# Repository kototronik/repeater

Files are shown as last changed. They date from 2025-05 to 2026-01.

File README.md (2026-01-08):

# Репитер на базе ESP32
## ⚠️ 

Проект больше не поддерживается.
Дальнейшее развитие и обновления не планируются.

---

## Основные возможности

- Повторение аналоговых FM-сигналов  
- Совместимость с радиостанциями с 6-пиновым разъёмом **Kenwood** (Baofeng, Kenwood, Quansheng и др.)  
- Подходит для стационарного и мобильного использования  

---

## Основные компоненты

- **Микроконтроллер** ESP32  
- **Радиостанция** с разъёмом Kenwood  
- **Источник питания** 5В  
- **Схема согласования и развязки аудиосигналов** (см. ниже)  
- **Внешний ЦАП** PCM5102A *(опционально)*  

---

## Схема подключения разъёма Kenwood

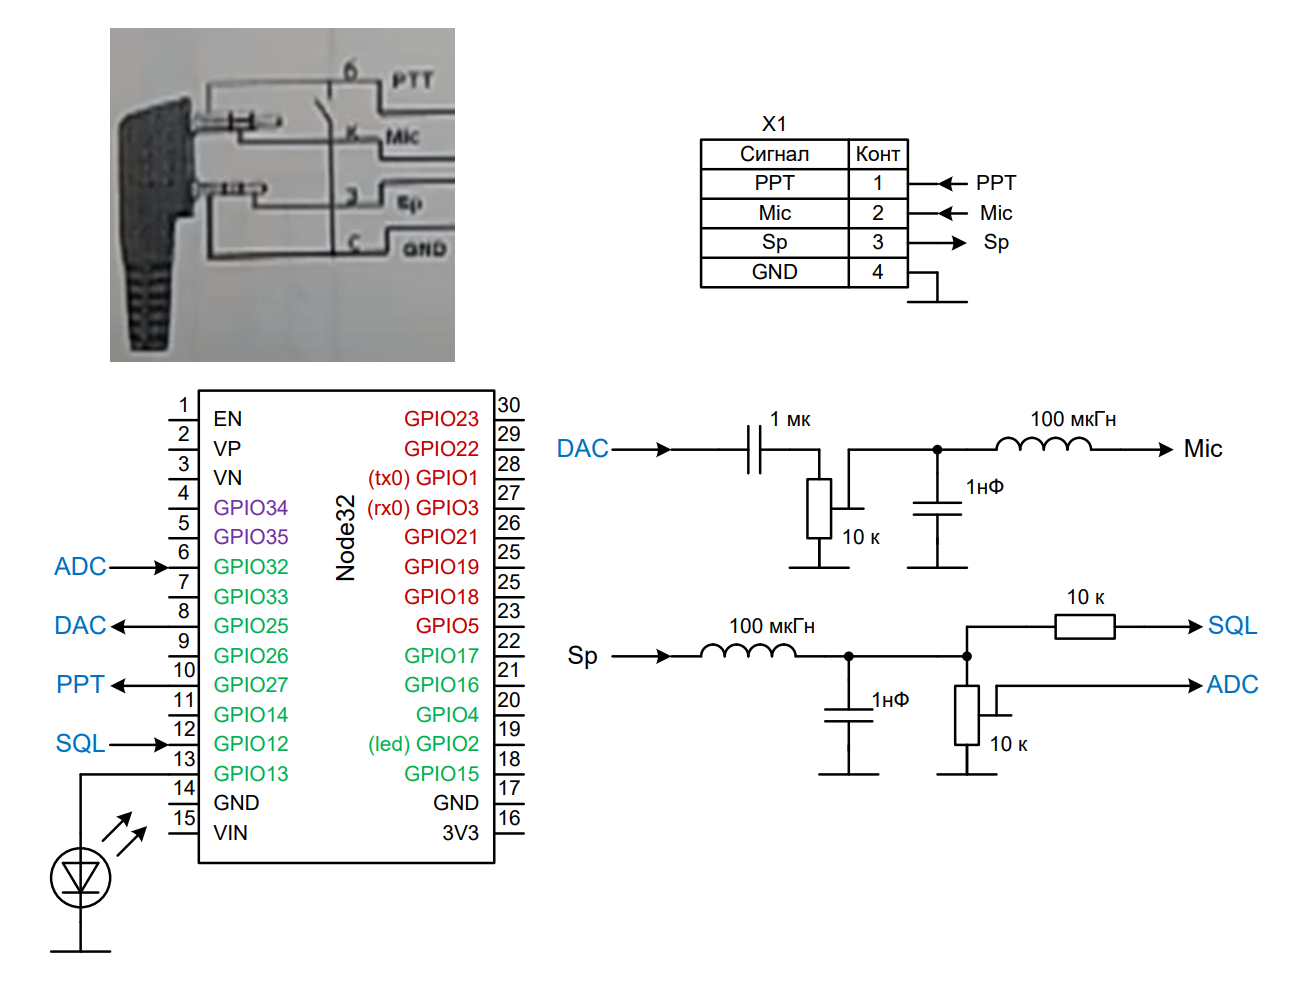
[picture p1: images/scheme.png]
Схема подключения разъема Kenwood


> **Примечание:** в версии с внешним ЦАПом пин **PTT = GPIO 32**

---

## Подключение SD-карты

| **SD-карта** | **ESP32** |
|---|---|
| CS | GPIO 5 |
| SCK | GPIO 18 |
| MOSI (SDI) | GPIO 23 |
| MISO (SDO) | GPIO 19 |
| VCC | 3.3В *(или 5В)* |
| GND | GND |

---

## Подключение внешнего ЦАП (PCM5102A)

| **ЦАП PCM5102A** | **ESP32** |
|---|---|
| DIN (DOUT) | GPIO 25 |
| BCK (BCLK) | GPIO 27 |
| LCK (LRCK) | GPIO 26 |
| VCC | 3.3В |
| GND | GND |

---

## Работоспособность

- **Встроенный ЦАП ESP32**  
  Работает, но присутствуют искажения и посторонние шумы. При слабом входном сигнале — плохая разборчивость речи.  

- **Внешний ЦАП (PCM5102A)**  
 При хорошем экранировании — качественное звучание.  

---

## Корпус

3D-модели корпуса и крышки находятся в папке `3D` (формат `.stp`).

---

## Источник

Проект основан на работе [Печенова Александра (ФГБОУ ВО "ДОННТУ", г. Донецк)](https://disk.yandex.ru/d/aPEOfnw8R4aH_Q).

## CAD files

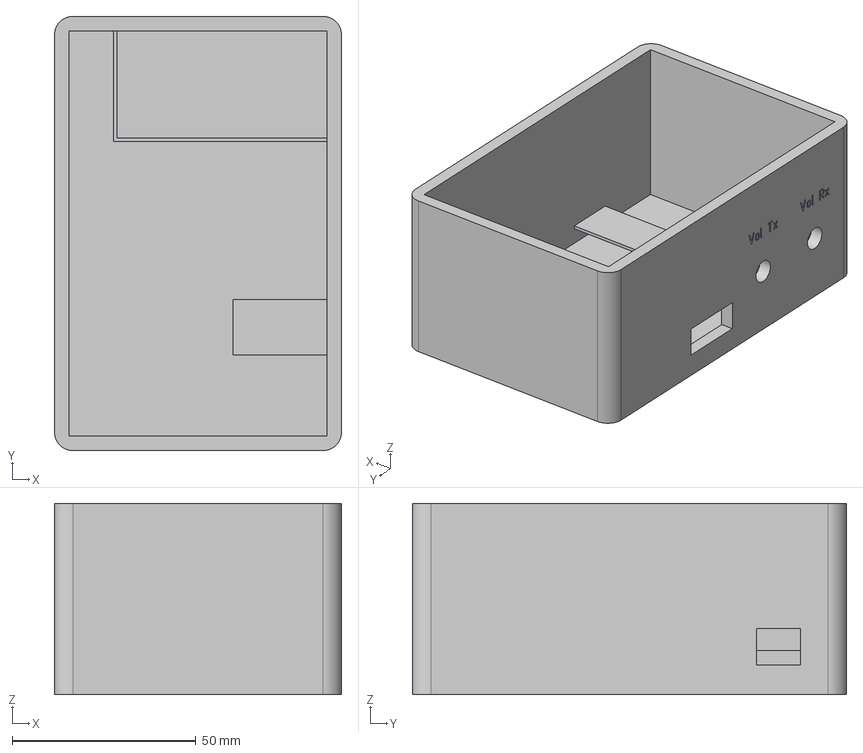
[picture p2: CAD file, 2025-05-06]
3D/репитер коробка.stp
78.0 x 118.0 x 52.0 mm

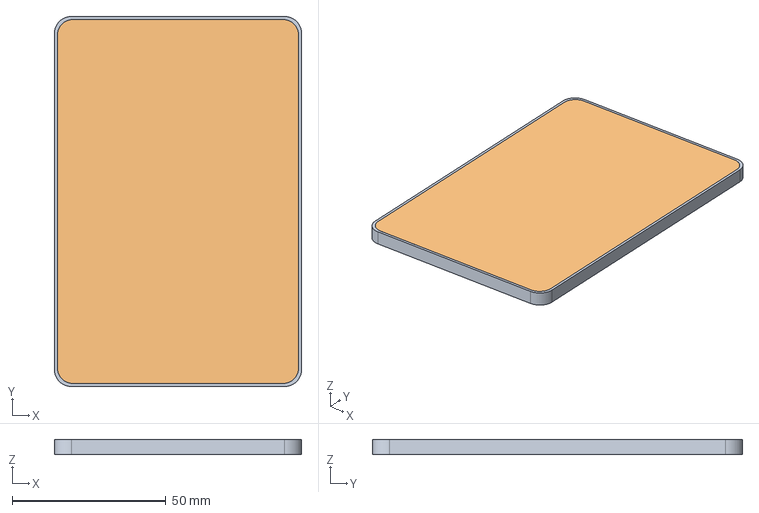
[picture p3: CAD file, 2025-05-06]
3D/крышка.stp
80.5 x 120.5 x 5.00 mm

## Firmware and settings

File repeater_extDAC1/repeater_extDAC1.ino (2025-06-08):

#include <Arduino.h>

#include <SD.h>

#include <FS.h>

#include "driver/i2s.h"

// === Константы ===

// === Настройки I2S ===
#define I2S_SAMPLE_RATE 22050 // Частота дискретизации
#define I2S_SAMPLE_BITS 16 // Битность выборки
#define I2S_CHANNEL_NUM 1
#define I2S_BUFFER_LEN 1024 // Размер буфера I2S

// === Пины подключения радиостанции ===
#define pinPPT 32
#define pinSQL 12

// === Пины подключения SD-карты и I2S ===
#define SD_CS_PIN 5
#define I2S_DOUT_PIN 25
#define I2S_BCLK_PIN 27
#define I2S_LRCK_PIN 26

const char * audioFileName = "/recording.wav"; // Имя файла для записи
File audioFile;

bool Rec = false; // Флаг записи

// === Конфигурация встроенного I2S (пин 36, ADC) ===
void setupI2S_Input() {
  i2s_config_t config = {
    .mode = (i2s_mode_t)(I2S_MODE_MASTER | I2S_MODE_RX | I2S_MODE_ADC_BUILT_IN),
    .sample_rate = I2S_SAMPLE_RATE,
    .bits_per_sample = I2S_BITS_PER_SAMPLE_16BIT,
    .channel_format = I2S_CHANNEL_FMT_ONLY_LEFT,
    .communication_format = I2S_COMM_FORMAT_STAND_I2S,
    .intr_alloc_flags = ESP_INTR_FLAG_LEVEL1,
    .dma_buf_count = 8,
    .dma_buf_len = I2S_BUFFER_LEN / 2,
    .use_apll = false,
    .tx_desc_auto_clear = false,
    .fixed_mclk = 0
  };
  i2s_driver_install(I2S_NUM_0, & config, 0, NULL);
  i2s_set_adc_mode(ADC_UNIT_1, ADC1_CHANNEL_0);
  i2s_adc_enable(I2S_NUM_0);
}

// === Конфигурация PCM5102A (DAC) ===
void setupI2S_Output() {
  i2s_config_t config = {
    .mode = (i2s_mode_t)(I2S_MODE_MASTER | I2S_MODE_TX),
    .sample_rate = I2S_SAMPLE_RATE,
    .bits_per_sample = I2S_BITS_PER_SAMPLE_16BIT,
    .channel_format = I2S_CHANNEL_FMT_ONLY_LEFT,
    .communication_format = I2S_COMM_FORMAT_STAND_I2S,
    .intr_alloc_flags = ESP_INTR_FLAG_LEVEL1,
    .dma_buf_count = 8,
    .dma_buf_len = I2S_BUFFER_LEN / 2,
    .use_apll = false,
    .tx_desc_auto_clear = true,
    .fixed_mclk = 0
  };
  i2s_driver_install(I2S_NUM_0, & config, 0, NULL);
  i2s_pin_config_t pin_config = {
    .bck_io_num = I2S_BCLK_PIN,
    .ws_io_num = I2S_LRCK_PIN,
    .data_out_num = I2S_DOUT_PIN,
    .data_in_num = I2S_PIN_NO_CHANGE
  };
  i2s_set_pin(I2S_NUM_0, & pin_config);
}

// === Прописывание wav заголовка ===
void writeWavHeader(File file, uint32_t dataSize) {
  uint32_t sampleRate = I2S_SAMPLE_RATE;
  uint16_t bitsPerSample = I2S_SAMPLE_BITS;
  uint16_t channels = I2S_CHANNEL_NUM;
  uint32_t byteRate = sampleRate * channels * (bitsPerSample / 8);
  uint16_t blockAlign = channels * (bitsPerSample / 8);
  uint32_t chunkSize = 36 + dataSize;

  file.seek(0);
  file.write((const uint8_t * )
    "RIFF", 4);
  file.write((uint8_t * ) & chunkSize, 4);
  file.write((const uint8_t * )
    "WAVE", 4);
  file.write((const uint8_t * )
    "fmt ", 4);

  uint32_t subchunk1Size = 16;
  uint16_t audioFormat = 1;

  file.write((uint8_t * ) & subchunk1Size, 4);
  file.write((uint8_t * ) & audioFormat, 2);
  file.write((uint8_t * ) & channels, 2);
  file.write((uint8_t * ) & sampleRate, 4);
  file.write((uint8_t * ) & byteRate, 4);
  file.write((uint8_t * ) & blockAlign, 2);
  file.write((uint8_t * ) & bitsPerSample, 2);
  file.write((const uint8_t * )
    "data", 4);
  file.write((uint8_t * ) & dataSize, 4);

}

// === Функция записи на карту ===
void recordWav() {
  uint8_t i2sBuffer[I2S_BUFFER_LEN];
  int16_t samples[I2S_BUFFER_LEN / 2];
  size_t bytesRead;
  uint32_t totalBytes = 0;

  float scaleFactor = 16.0f;
  float fc = 70.0f;
  float fs = I2S_SAMPLE_RATE;
  float RC = 1.0f / (2.0f * PI * fc);
  float alpha = RC / (RC + 1.0f / fs);

  int16_t x_prev = 0, y_prev = 0;

  Serial.println("Начинаем запись...");

  unsigned long lastSignalTime = millis(); // Время последнего сигнала
  const unsigned long signalTimeout = 1000; // Таймаут "тишины" в миллисекундах

  while (true) {
    bool signal = digitalRead(pinSQL);
    if (signal) {
      lastSignalTime = millis(); // Обновляем время последнего сигнала
    }

    if (millis() - lastSignalTime > signalTimeout) {
      // Если сигнал не поступает в течение заданного времени (1000 мс), завершаем запись
      break;
    }

    if (i2s_read(I2S_NUM_0, i2sBuffer, I2S_BUFFER_LEN, & bytesRead, portMAX_DELAY) != ESP_OK)
      continue;

    int sampleCount = bytesRead / 2;
    for (int i = 0; i < sampleCount; ++i) {
      uint16_t raw = ((uint16_t) i2sBuffer[i * 2 + 1] << 8) | i2sBuffer[i * 2];
      int16_t centered = (int16_t) raw - 2048;
      int32_t scaled = centered * scaleFactor;
      scaled = constrain(scaled, -32768, 32767);
      int16_t current = scaled;
      int16_t filtered = alpha * (y_prev + current - x_prev);
      x_prev = current;
      y_prev = filtered;
      samples[i] = filtered;
    }

    audioFile.write((uint8_t * ) samples, sampleCount * sizeof(int16_t));
    totalBytes += sampleCount * sizeof(int16_t);
  }

  Serial.println("Запись завершена.");
  writeWavHeader(audioFile, totalBytes);
}

// === Функция воспроизведения ===
void playWav(const char * filePath) {
  File file = SD.open(filePath, FILE_READ);
  if (!file || file.size() <= 44) {
    Serial.println("Ошибка WAV-файла.");
    return;
  }

  uint8_t buffer[I2S_BUFFER_LEN];
  size_t bytesRead, bytesWritten;

  Serial.print("Воспроизведение: ");
  Serial.println(filePath);

  file.seek(44); // Пропускаем заголовок WAV, так как и так знаем параметры записи, он нужен только для упрощения воспроизведения на компьютере
  while (file.available()) {
    bytesRead = file.read(buffer, I2S_BUFFER_LEN);
    i2s_write(I2S_NUM_0, buffer, bytesRead, & bytesWritten, portMAX_DELAY);
  }

  i2s_zero_dma_buffer(I2S_NUM_0);
  file.close();
  Serial.println("Готово.");
}

void setup() {
  Serial.begin(115200);

  pinMode(pinPPT, INPUT);
  pinMode(pinSQL, INPUT);

  Serial.print("SD карта: "); // Инициализация SD-карты
  if (!SD.begin(SD_CS_PIN)) {
    Serial.println("ошибка инициализации... проверьте подключение.");
    while (true);
  }
  Serial.println("репитер готов к исползованию!");

}

void loop() {
  bool SQL = digitalRead(pinSQL);

  //Условие для начала записи
  if (SQL && !Rec) {
    Rec = true;

    if (SD.exists(audioFileName)) SD.remove(audioFileName);
    audioFile = SD.open(audioFileName, FILE_WRITE);
    if (!audioFile) {
      Serial.println("Не удалось открыть файл.");
      return;
    }

    uint8_t header[44] = {
      0
    };
    audioFile.write(header, 44);

    setupI2S_Input();
    recordWav();
    i2s_adc_disable(I2S_NUM_0);
    i2s_driver_uninstall(I2S_NUM_0);
    audioFile.close();

    delay(500);

    pinMode(pinPPT, OUTPUT);
    setupI2S_Output();
    playWav(audioFileName); //Повторяем то, что записали
    playWav("/end2.wav"); //Воспроизводим сигнал окончания передачи
    i2s_driver_uninstall(I2S_NUM_0);

    Rec = false;
    pinMode(pinPPT, INPUT);
  }

}

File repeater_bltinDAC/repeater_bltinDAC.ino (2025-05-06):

#include <SD.h>

#include <FS.h>

#define dt 110 // Период квантования ЦАП, мкс
#define pinLED 2 // Встроенный светодиод
#define pinLED2 13 // Внешний светодиод
#define pinADC 32 // АЦП
#define pinDAC 25 // ЦАП
#define pinPPT 27 // Программный аналог кнопки PTT
#define pinSQL 12 // Триггер записи (радиостанция, при открытии шумоподавителя, посылает постоянный ток на этот пин)
#define morseFreq 1000 // Несущая частота морзянки (завершение передачи будет на этой частоте)

long T_dt; // Таймер воспроизведения
bool Rec = false; // Флаг записи

File audioFile;

void setup() {
  setCpuFrequencyMhz(40); //Включение экономии энергии

  pinMode(pinLED, OUTPUT);
  pinMode(pinLED2, OUTPUT);

  digitalWrite(pinLED2, 1);
  delay(1000);
  digitalWrite(pinLED2, 0);

  pinMode(pinPPT, INPUT);
  pinMode(pinSQL, INPUT);

  Serial.begin(9600);
  Serial.println("start");

  if (!SD.begin()) {
    Serial.println("Ошибка инициализации SD-карты!");
    return;
  }
  Serial.println("SD карта инициализирована");
}

void playMorseSymbol(bool isDot) {
  unsigned long duration = isDot ? 50 : 150; // 50 мс для точки, 150 мс для тире
  unsigned long startTime = millis();

  // Генерация сигнала с частотой morseFreq Гц (с использованием прямоугольного сигнала через ЦАП)
  while (millis() - startTime < duration) {
    dacWrite(pinDAC, 255); // Выводим высокий уровень (максимальное значение для аналогового сигнала, доступного для встроенного АЦП)
    delayMicroseconds(500); // Высокий уровень для полуволны
    dacWrite(pinDAC, 0); // Выводим низкий уровень
    delayMicroseconds(500); // Низкий уровень для полуволны
  }

  delay(50); // Интервал между символами
}

void playMorseCode() {
  // Морзянка для "*-*-*" (с быстрым интервалом между символами)
  playMorseSymbol(true);  // *
  playMorseSymbol(false); // -
  playMorseSymbol(true);  // *
  playMorseSymbol(false); // -
  playMorseSymbol(true);  // *
}

void loop() {
  bool SQL = digitalRead(pinSQL);
  digitalWrite(pinLED2, SQL); // Индикация записи

  // Начало записи
  if (SQL && !Rec) {
    Rec = true;
    setCpuFrequencyMhz(240); // Выход из режима экономии
    T_dt = micros();

    // Открываем файл для записи
    audioFile = SD.open("/audio.dat", FILE_WRITE);
    if (!audioFile) {
      Serial.println("Ошибка открытия файла для записи!");
      Rec = false;
      return;
    }

    Serial.println("Начало записи...");
  }

  // Запись данных на SD пока активен pinSQL
  unsigned long silenceStart = 0;

  while (Rec) {
    bool currentSQL = digitalRead(pinSQL);

    if (currentSQL) {
      silenceStart = 0; // сбрасываем таймер тишины

      if (micros() - T_dt >= dt) {
        T_dt = micros();
        byte value = analogRead(pinADC) / 16; // Преобразуем 12-бит в 8-бит
        audioFile.write(value);
      }
    } else {
      if (silenceStart == 0) {
        silenceStart = millis(); // фиксируем момент начала тишины
      } else if (millis() - silenceStart >= 1000) {
        break; // тишина более 1 секунды - прерываем запись
      }
    }
  }

  // Завершение записи и начало воспроизведения
  if (Rec && digitalRead(pinSQL) == 0) {
    Rec = false;
    audioFile.close();
    Serial.println("Запись завершена");
    delay(1000);

    // Переход к передаче
    pinMode(pinPPT, OUTPUT);
    Serial.println("Передача...");

    File playFile = SD.open("/audio.dat");
    if (playFile) {
      unsigned long T_play = micros();
      while (playFile.available()) {
        byte val = playFile.read();
        dacWrite(pinDAC, val);

        // Воспроизведение
        while (micros() - T_play < dt) {
          // ждём до наступления следующего квантования
        }
        T_play += dt;

        if (playFile.position() % 1000 == 0)
          digitalWrite(pinLED2, !digitalRead(pinLED2));
      }
      playFile.close();
      playMorseCode(); // Воспроизведение морзянки после аудио
    }

    digitalWrite(pinLED2, 0);
    delay(500);
    pinMode(pinPPT, INPUT);
    setCpuFrequencyMhz(40);
    Serial.println("Передача завершена");

  }
}

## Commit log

2025-05-06 Добавлен основной код прошивки для ESP32
    ЭТО - БЕТА ВЕРСИЯ. Проект еще сыроват, но уже допускает использование.
    Из недостатков: Не очень красивая модуляция, за счет использования встроенного ЦАП в ESP32 (он 8- битный), а также, слышны тики каждую секунду, они почти не влияют на разборчивость речи, но устранять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
    В целом, этой версией пользоваться уже можно, закрывая глаза на эти не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
2025-05-06 Добавлена схема распайки разьема к плате
2025-05-06 Подредактирован ридмик
2025-05-06 Добавлена папка для изображений, схема переехала туда
2025-05-06 Случайно переместил папки не туда, возвращаю
    [крышка.stp, репитер коробка.stp]
2025-05-06 расширение ридмишки
2025-05-06 исправление недочетов ридмишки
2025-05-06 доработка ридми
2025-06-02 Добавление версии с внешним цап, обновление readme
2025-06-08 украшатель кода добавил пару лишних пробелов, удалил, теперь компилируется
